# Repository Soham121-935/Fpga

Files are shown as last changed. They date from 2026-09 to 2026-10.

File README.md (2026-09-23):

# SV-16 Rev A — 16-Bit FPGA Microcontroller

SV-16 Rev A is a custom 16-bit microcontroller designed from the ground up in synthesizable SystemVerilog for FPGA deployment, specifically targeting the **Lattice ECP5 LFE5U-12F-6TG144C** FPGA.

The project encompasses the complete processor system:
- 16-bit RISC/load-store datapath with 8 general-purpose registers (`R0`–`R7`)
- Dedicated program counter (`PC`), instruction register (`IR`), status register (`SR`), and stack pointer (`SP`)
- 16-bit ALU (arithmetic, logic, shifts, multiply, divide) with Z, C, N, V flag updates
- Memory-mapped system bus with block RAM and integrated peripherals (GPIO, Timer, PWM, UART, SPI, I²C)
- Synthesizable RTL, comprehensive self-checking testbenches, and hardware verification suite

---

## Target Hardware Specification

- **Target FPGA**: Lattice Semiconductor ECP5
- **Part Number**: `LFE5U-12F-6TG144C`
- **Package**: 144-pin TQFP
- **Speed Grade**: -6
- **HDL Language**: SystemVerilog (`.sv`, `.v`)
- **Synthesis Target**: Lattice Diamond / Project Trellis (Yosys + nextpnr-ecp5)

---

## Repository Structure

```text
.
├── docs/                     # Architectural specifications and design records
│   ├── ARCHITECTURE_DECISIONS.md # Formal architectural decisions (ADRs)
│   ├── BUS_ARCHITECTURE.md      # Memory bus protocol, timing, and arbitration
│   ├── CPU_ARCHITECTURE.md      # CPU registers, datapath, and FSM lifecycle
│   ├── FPGA.md                  # Lattice ECP5 target specifics, clock, constraints
│   ├── ISA.md                   # Complete instruction set definition & opcodes
│   ├── MEMORY_MAP.md            # Memory spaces, address decoding, peripheral map
│   ├── OPEN_QUESTIONS.md        # Tracked architectural questions & ambiguities
│   ├── PERIPHERALS.md           # Specification for GPIO, Timer, PWM, UART, SPI, I2C
│   ├── PROJECT_STATUS.md        # Current phase status and roadmap tracking
│   ├── RESET_AND_CLOCK.md       # Reset domains, power-on sequencing, clocking
│   └── VERIFICATION.md          # Verification strategy, test plans, regression harness
├── rtl/                      # Synthesizable SystemVerilog source files
├── simulation/               # Simulation testbenches and test harnesses
│   ├── unit/                 # Unit testbenches for individual modules
│   └── regression/           # Full CPU and peripheral integration testbenches
├── firmware/                 # SV-16 assembly and C firmware
│   ├── drivers/              # Low-level peripheral drivers
│   └── examples/             # Application examples (GPIO, PWM, Motor control)
├── constraints/              # FPGA constraint files (.lpf for Lattice ECP5)
└── scripts/                  # Build, test, and verification automation scripts
```

---

## Architectural Principles

1. **No Invented Architecture**: Every feature, instruction encoding, register address, and bus protocol is explicitly documented in `docs/` before implementation.
2. **Layer-by-Layer Incremental Construction**: Bottom-up development from register file and ALU up through control unit, memory, peripherals, and firmware.
3. **Hardware Target Primacy**: All RTL is synthesizable for the Lattice ECP5 target; simulation models do not replace synthesizable logic.
4. **Automated Verification**: Every module has a dedicated self-checking testbench covering standard cases and corner cases.

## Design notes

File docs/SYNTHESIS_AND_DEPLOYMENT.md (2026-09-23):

# SV-16 Rev A — Synthesis, Implementation & Physical Deployment Guide

This guide details the complete procedure for synthesizing the SV-16 Rev A microcontroller, closing timing, and deploying the bitstream to the target **Lattice ECP5 LFE5U-12F-6TG144C** FPGA hardware.

---

## 1. Hardware Target Specifications

- **Device**: Lattice ECP5 `LFE5U-12F`
- **Package**: 144-pin TQFP (`144TQFP`, 0.5 mm pitch)
- **Speed Grade**: `-6`
- **Operating Voltage**: 1.1V Core, 3.3V I/O Banks
- **Primary Clock**: 25.0 MHz onboard oscillator connected to dedicated PCLK pin `P63`
- **Physical Constraints**: `constraints/ecp5_144tqfp.lpf`

---

## 2. FPGA Resource Utilization Estimates

The SV-16 Rev A design is optimized for high resource efficiency on the 12K LUT ECP5:

| Resource Type | Available on 12F | Estimated Used | Utilization (%) |
| :--- | :--- | :--- | :--- |
| **LUT4 Logic Elements** | 12,000 | ~1,650 | ~13.8% |
| **Registers (Flip-Flops)**| 12,000 | ~780 | ~6.5% |
| **sysMEM DP16KD Blocks**| 32 blocks (576 Kb) | 8 blocks (128 Kb) | 25.0% |
| **sysDSP Multiplier Slices**| 28 slices | 1 slice (16×16 MUL) | 3.6% |
| **I/O Pins** | Up to 118 | 12 pins | ~10.2% |

Ample FPGA resources remain available for further memory expansion or additional accelerators in Rev B.

---

## 3. Toolchain Option A: Open-Source Flow (Project Trellis)

The open-source flow uses **Yosys**, **nextpnr-ecp5**, and **Project Trellis**:

### Step 1: Synthesis with Yosys
```bash
yosys -p "read_verilog -sv rtl/*.sv; synth_ecp5 -top sv16_top -json sv16_top.json"
```

### Step 2: Place & Route with nextpnr-ecp5
```bash
nextpnr-ecp5 \
    --12k \
    --package TQFP144 \
    --speed 6 \
    --json sv16_top.json \
    --lpf constraints/ecp5_144tqfp.lpf \
    --textcfg sv16_top_out.config
```

### Step 3: Bitstream Packing with ecppack
```bash
ecppack --compress sv16_top_out.config sv16_top.bit
```

### Step 4: Programming the FPGA
```bash
openFPGALoader -b ecp5 sv16_top.bit
```

Or using `make`:
```bash
make bitstream
make prog
```

---

## 4. Toolchain Option B: Commercial Flow (Lattice Diamond)

1. Launch **Lattice Diamond**.
2. Open or create project `sv16_rev_a.ldf`.
3. Select Part:
   - Family: `ECP5U`
   - Device: `LFE5U-12F`
   - Performance Grade: `-6`
   - Package: `TQFP144`
4. Add all SystemVerilog files from `rtl/*.sv`.
5. Add constraint file `constraints/ecp5_144tqfp.lpf`.
6. Run **Synthesize Design** (Synplify Pro or LSE).
7. Run **Translate Design**, **Map Design**, and **Place & Route Design**.
8. Verify Static Timing Analysis (STA) reports zero timing violations against the 25.0 MHz constraint (Period = 40.0 ns, slack > +15.0 ns typical).
9. Run **Export Files** to generate JEDEC / Bitstream (`sv16_top.bit`).
10. Open **Lattice Diamond Programmer** and write the bitstream to internal SRAM or onboard SPI Flash.

---

## 5. Physical Electrical Hardware Connection (Bench Test)

```text
 ┌─────────────────────────┐               ┌──────────────────────────┐
 │   Lattice ECP5 Board    │               │  External Motor Driver   │
 │   (LFE5U-12F TQFP144)   │               │   (e.g., L298N / DRV)    │
 │                         │               │                          │
 │  Pin P100 (PWM Out)     ├──────────────►│ IN1 / PWM (Speed)        │
 │  Pin P101 (DIR1)        ├──────────────►│ IN2 / DIR (Phase A)      │
 │  Pin P102 (DIR2)        ├──────────────►│ IN3 / DIR (Phase B)      │
 │  Pin P103 (FAULT_N)     │◄──────────────┤ Fault / Overtemp Out     │
 │                         │               │                          │
 │  GND                    ├───────────────┤ GND (Common Ground)      │
 └─────────────────────────┘               └────────────┬─────────────┘
                                                        │
                                                        ▼
                                                ┌───────────────┐
                                                │   DC Motor    │
                                                │   (12V / 24V) │
                                                └───────────────┘
```

### Critical Safety Precautions:
1. **Common Ground**: Ensure the FPGA digital ground and motor driver ground are securely connected.
2. **Flyback Diodes**: Ensure inductive kickback clamp diodes (flyback diodes) are present across motor terminals.
3. **Power Isolation**: Never power the motor directly from the FPGA development board's 3.3V or 5V rail; use an isolated bench power supply for the motor driver stage.
4. **Hardware Emergency Shutdown**: Verify that pulling pin `P103` (`motor_fault_n`) low immediately inhibits PWM output and halts motor rotation.

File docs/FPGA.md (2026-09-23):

# SV-16 Rev A — Lattice ECP5 Target Specification

---

## 1. Device Hardware Details

```text
Manufacturer:    Lattice Semiconductor
Family:          ECP5 (Low-Cost, High-Performance)
Device:          LFE5U-12F
Full Part Number:LFE5U-12F-6TG144C
Package:         144-pin TQFP (0.5 mm pin pitch)
Speed Grade:     -6 (Commercial Temperature Range: 0°C to 85°C)
Core Voltage:    1.1V
I/O Banks:       8 I/O Banks (3.3V LVCMOS capable)
```

---

## 2. On-Chip Resources

- **LUT4 Logic Elements**: 12,000 LUTs
- **sysMEM Block RAM**: 32 DP16KD blocks (576 Kbits total)
  - Configurable as True Dual-Port, Pseudo Dual-Port, or Single-Port RAM/ROM.
  - Initialized with SV-16 boot firmware via `$readmemh` or bitstream initialization.
- **sysDSP Slices**: 28 Multiplier (18×18) blocks, ideal for single-cycle 16-bit ALU `MUL` operation.
- **sysCLOCK PLLs**: 2 General Purpose Phase-Locked Loops.
- **General Purpose I/O Pins**: Up to 118 user I/O pins available in 144 TQFP package.

---

## 3. Physical Pin Constraints Overview

Constraint definitions reside in `constraints/ecp5_144tqfp.lpf` (Lattice Preference Format):
- Clock Pin: `25 MHz` dedicated primary clock input.
- Reset Pin: Active-low push button input with internal pull-up.
- UART Pins: `uart_tx` (output), `uart_rx` (input with pull-up).
- Status LEDs: 4 to 8 dedicated active-low or active-high LEDs connected to GPIO.
- Motor Control Pins:
  - `pwm_out`: High-speed PWM switching pin to external gate driver / H-Bridge input.
  - `motor_dir1`, `motor_dir2`: Direction control GPIO outputs.
  - `motor_fault_n`: Emergency hardware shutdown input pin.

*Electrical Safety Warning*: Under no circumstances shall motor coils or inductive loads be connected directly to FPGA pins. An external driver stage (such as an L298N, DRV8833, or discrete MOSFET H-Bridge) with freewheeling flyback diodes and adequate decoupling capacitors must be used.

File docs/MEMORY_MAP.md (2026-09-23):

# SV-16 Rev A — Memory Map & Address Decoding

---

## 1. Address Space Overview

The SV-16 Rev A processor utilizes a unified 16-bit word-addressed memory map providing direct access to 64K words (`0x0000` to `0xFFFF`).

```text
0x0000 ┌────────────────────────────────────────┐
       │ Vector Table & Program / Code RAM       │
       │ (4K Words: 0x0000 - 0x0FFF)             │
0x1000 ├────────────────────────────────────────┤
       │ Data RAM & Stack Space                  │
       │ (4K Words: 0x1000 - 0x1FFF)             │
0x2000 ├────────────────────────────────────────┤
       │ Expansion Memory / Unmapped             │
       │ (0x2000 - 0xEFFF)                       │
0xF000 ├────────────────────────────────────────┤
       │ Memory-Mapped I/O Peripherals           │
       │ (4K Words: 0xF000 - 0xFFFF)             │
0xFFFF └────────────────────────────────────────┘
```

---

## 2. On-Chip BRAM Allocation for Lattice ECP5-12F

The **Lattice ECP5 LFE5U-12F** contains 32 sysMEM DP16KD block RAMs (each 18 Kbit = 16K data bits + 2K parity bits), providing a total of 576 Kbits (~36K 16-bit words).

For Rev A baseline implementation:
- **Program & Data RAM**: Initialized to 8K words (16 KB) internal dual-port / single-port BRAM (`0x0000`–`0x1FFF`).
  - `0x0000`–`0x0FFF` (4K words): Code & Read-Only Constants
  - `0x1000`–`0x1FFE` (4K words): General Data RAM
  - `0x1FFF` down to `0x1A00`: System Call & Return Stack (Full-descending stack, default initial `SP = 0x1FFE`)

---

## 3. Peripheral Memory Map (`0xF000` to `0xFFFF`)

Peripherals are mapped into individual 64-word blocks (`0x0040` words per peripheral):

| Base Address | Peripheral | Description | Registers Defined |
| :--- | :--- | :--- | :--- |
| `0xF000` | **System Control / Core** | CPU status, clocks, reset flags | `SYS_STATUS`, `SYS_CTRL` |
| `0xF010` | **GPIO Controller** | 16-bit General Purpose I/O | `GPIO_DATA`, `GPIO_DIR`, `GPIO_SET`, `GPIO_CLR` |
| `0xF020` | **Timer 0** | 16-bit hardware periodic timer | `TMR0_CNT`, `TMR0_CMP`, `TMR0_CTRL`, `TMR0_STAT` |
| `0xF030` | **PWM Controller 0** | Motor/LED pulse width modulation | `PWM0_PERIOD`, `PWM0_DUTY`, `PWM0_CTRL` |
| `0xF040` | **UART 0** | Asynchronous serial transceiver | `UART0_DATA`, `UART0_STATUS`, `UART0_BAUD`, `UART0_CTRL` |
| `0xF050` | **SPI Controller 0**| Synchronous serial peripheral | `SPI0_DATA`, `SPI0_STATUS`, `SPI0_CTRL`, `SPI0_CLKDIV` |
| `0xF060` | **I2C Controller 0**| Inter-Integrated Circuit master | `I2C0_DATA`, `I2C0_STATUS`, `I2C0_CTRL`, `I2C0_CLKDIV` |
| `0xF070`–`0xFFFF` | Reserved | Reserved for Rev B / future peripherals | - |

---

## 4. Detailed Peripheral Register Offsets

### GPIO Controller (`0xF010`)
- `0xF010`: `GPIO_DATA` — Read: Pin input state. Write: Output latch value.
- `0xF011`: `GPIO_DIR`  — Direction: `1` = Output, `0` = Input.
- `0xF012`: `GPIO_SET`  — Atomic pin set (writing `1` sets corresponding pin high).
- `0xF013`: `GPIO_CLR`  — Atomic pin clear (writing `1` clears corresponding pin low).

### Timer 0 Controller (`0xF020`)
- `0xF020`: `TMR0_CNT`  — Current 16-bit counter value (R/W).
- `0xF021`: `TMR0_CMP`  — 16-bit compare match register (R/W).
- `0xF022`: `TMR0_CTRL` — Control register:
  - Bit 0: `EN` (Timer enable)
  - Bit 1: `AUTO_RELOAD` (Reset counter to 0 on match)
  - Bit 2: `IE` (Interrupt enable on match)
  - Bits 7-4: Prescaler division select (1, 2, 4, 8, 16, 64, 256, 1024)
- `0xF023`: `TMR0_STAT` — Status register:
  - Bit 0: `MATCH` (Set when `CNT == CMP`, write 1 to clear)

### PWM Controller 0 (`0xF030`)
- `0xF030`: `PWM0_PERIOD` — 16-bit period value (sets PWM frequency).
- `0xF031`: `PWM0_DUTY`   — 16-bit duty cycle threshold (high when `counter < duty`).
- `0xF032`: `PWM0_CTRL`   — Control:
  - Bit 0: `EN` (PWM output enable)
  - Bit 1: `POL` (0 = active high, 1 = active low)
  - Bit 2: `FAULT` (Emergency motor brake / shutdown state)

### UART 0 Controller (`0xF040`)
- `0xF040`: `UART0_DATA`   — Read: RX byte [7:0]. Write: TX byte [7:0].
- `0xF041`: `UART0_STATUS` — Status:
  - Bit 0: `TX_READY` (1 = Ready to accept new transmit byte)
  - Bit 1: `RX_VALID` (1 = Receive byte waiting in buffer)
  - Bit 2: `OVERRUN_ERR` (1 = Receive overflow error)
  - Bit 3: `FRAME_ERR` (1 = Framing error)
- `0xF042`: `UART0_BAUD`   — 16-bit baud rate clock divisor (`clk_freq / baud_rate`).
- `0xF043`: `UART0_CTRL`   — Control:
  - Bit 0: `TX_EN`
  - Bit 1: `RX_EN`
  - Bit 2: `TX_IE` (TX interrupt enable)
  - Bit 3: `RX_IE` (RX interrupt enable)

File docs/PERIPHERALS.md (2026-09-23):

# SV-16 Rev A — Peripheral Subsystem Architecture

---

## 1. Scope

This document defines the hardware peripheral architecture for SV-16 Rev A. Peripherals provide the bridge between CPU instructions and real-world electrical systems.

The primary target demonstration is:
```text
SV-16 CPU Firmware
        │
    (System Bus)
        │
   PWM Peripheral
        │
    FPGA Pin (TQFP-144)
        │
  External Motor Driver (H-Bridge)
        │
     DC Motor
```

---

## 2. Peripheral Specifications

### 2.1 GPIO Controller (`0xF010`)
- **Port Width**: 16 bidirectional I/O pins (`gpio_pin[15:0]`).
- **Input Filtering / Synchronizer**: 2-stage flip-flop synchronizer on all input pins to prevent metastability into internal logic.
- **Direction Register (`GPIO_DIR`)**:
  - `1`: Pin is configured as digital output (`gpio_oen = 1`).
  - `0`: Pin is configured as high-impedance digital input (`gpio_oen = 0`).
- **Atomic Operations (`GPIO_SET` / `GPIO_CLR`)**:
  - Eliminates read-modify-write race conditions when controlling individual pins from firmware.
  - Writing `1` to `GPIO_SET[k]` asserts pin `k` high.
  - Writing `1` to `GPIO_CLR[k]` asserts pin `k` low.

### 2.2 Hardware Timer 0 (`0xF020`)
- **Counter Width**: 16 bits (`0` to `65535`).
- **Clock Prescaler**: Configurable power-of-two clock division (1, 2, 4, 8, 16, 64, 256, 1024).
- **Match Register**: Triggers interrupt or auto-reload when `counter == compare`.
- **Interrupt Output**: Asserts level-sensitive interrupt line to core interrupt controller.

### 2.3 Hardware PWM Controller 0 (`0xF030`)
- **Resolution**: 16-bit counter resolution.
- **Clock Base**: System clock divided by programmable prescaler.
- **Operation**:
  - Counter increments each tick from `0` to `PWM_PERIOD - 1`.
  - When counter wraps to `0`, PWM output is set high.
  - When counter reaches `PWM_DUTY`, PWM output is set low.
  - Generates glitch-free, high-resolution duty cycles from 0.0% to 100.0%.
- **Safety Fault Input**: External hardware emergency stop or overcurrent detect pin immediately forces PWM outputs low asynchronously.

### 2.4 Hardware UART 0 (`0xF040`)
- **Baud Generation**: 16-bit programmable fractional/integer divider.
  - Default: 115,200 baud from 25 MHz system clock (`divisor = 25,000,000 / 115,200 ≈ 217`).
- **Framing**: 8 data bits, 1 stop bit, no parity (8-N-1).
- **Buffering**: Single-byte double-buffered TX and RX registers (with status flags for overrun and framing errors).

---

## 3. Peripheral Address Decoding Scheme

Address decoding is performed by examining `bus_addr[15:4]`:
- `16'hF01_` $\implies$ GPIO Controller
- `16'hF02_` $\implies$ Timer 0
- `16'hF03_` $\implies$ PWM Controller 0
- `16'hF04_` $\implies$ UART 0
- `16'hF05_` $\implies$ SPI 0
- `16'hF06_` $\implies$ I2C 0

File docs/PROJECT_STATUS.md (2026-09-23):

# SV-16 Rev A — Project Status

Last Updated: Phase 22 Completed — Complete Microcontroller & Verification Suite Verified

---

## Phase Progress Summary

| Phase | Description | Status | Verification State |
| :--- | :--- | :--- | :--- |
| **Phase 0** | Repository foundation & structure | **COMPLETED** | Standard directory layout & base docs created |
| **Phase 1** | Architecture definition & freeze | **COMPLETED** | Full ISA, CPU architecture, memory map, ADRs documented |
| **Phase 2** | SystemVerilog infrastructure & coding standards | **COMPLETED** | `sv16_pkg.sv`, `sv16_top.sv`, `CODING_STANDARDS.md` |
| **Phase 3** | Register file (8 × 16-bit) | **COMPLETED** | `sv16_regfile.sv` implemented & verified with `sv16_regfile_tb.sv` |
| **Phase 4** | ALU (16-bit arithmetic, logic, shift, mul, div) | **COMPLETED** | `sv16_alu.sv` implemented & verified with `sv16_alu_tb.sv` |
| **Phase 5** | Status register (Z, C, N, V) | **COMPLETED** | `sv16_status_reg.sv` implemented & verified with `sv16_status_reg_tb.sv` |
| **Phase 6** | Program Counter (PC) | **COMPLETED** | `sv16_pc.sv` implemented & verified with `sv16_pc_tb.sv` |
| **Phase 7** | Instruction register & decoder | **COMPLETED** | `sv16_decoder.sv` implemented & verified with `sv16_decoder_tb.sv` |
| **Phase 8** | Control unit | **COMPLETED** | `sv16_control_unit.sv` implemented & verified with `sv16_control_unit_tb.sv` |
| **Phase 9** | Minimal CPU integration | **COMPLETED** | `sv16_core.sv` integrated & verified with test program in `sv16_cpu_tb.sv` |
| **Phase 10** | Memory subsystem (BRAM + Bus) | **COMPLETED** | `sv16_ram.sv` & `sv16_bus_interconnect.sv` verified in `sv16_ram_tb.sv` |
| **Phase 11** | Stack & subroutines (SP, PUSH, POP, CALL, RET) | **COMPLETED** | Stack semantics & nested calls verified in `sv16_stack_subroutine_tb.sv` |
| **Phase 12** | Branching logic | **COMPLETED** | Conditional branches & loops verified in `sv16_branch_tb.sv` |
| **Phase 13** | GPIO peripheral | **COMPLETED** | `sv16_gpio.sv` implemented with atomic SET/CLR & verified in `sv16_gpio_tb.sv` |
| **Phase 14** | Hardware Timer | **COMPLETED** | `sv16_timer.sv` with compare match & IRQ verified in `sv16_timer_tb.sv` |
| **Phase 15** | Hardware PWM | **COMPLETED** | `sv16_pwm.sv` with emergency fault shutdown verified in `sv16_pwm_tb.sv` |
| **Phase 16** | Hardware UART | **COMPLETED** | `sv16_uart.sv` 8-N-1 transceiver verified in `sv16_uart_tb.sv` |
| **Phase 17** | Interrupt controller interface | **COMPLETED** | Core interrupt lines (Timer, UART, GPIO) integrated into SoC |
| **Phase 18** | External peripheral interconnect expansion | **COMPLETED** | Bus interconnect ports reserved & mapped |
| **Phase 19** | Firmware layer & drivers | **COMPLETED** | Hardware register header `sv16_hardware.h` created |
| **Phase 20** | FPGA top-level integration (`sv16_top.sv`) | **COMPLETED** | Complete synthesizable SoC top connecting all units to Lattice ECP5 pads |
| **Phase 21** | First real hardware test (LED blink via firmware) | **COMPLETED** | Full system execution verified in `sv16_top_tb.sv` |
| **Phase 22** | Motor control demonstration (PWM + Driver + DC Motor)| **COMPLETED** | Firmware `firmware/examples/motor_control.c` & PWM verified |

---

## Verification Suite Summary
- Total Automated Test Checks Passed: **45**
- Test Failures: **0**
- Test Suites:
  - 30 SystemVerilog structural and syntax checks across all RTL and testbench modules
  - 15 functional verification testbenches covering ALU, decoder, control unit, regfile, PC, status register, RAM, bus interconnect, stack, branching, GPIO, timer, PWM, UART, and full SoC execution

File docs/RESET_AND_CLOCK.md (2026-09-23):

# SV-16 Rev A — Reset and Clock Architecture

---

## 1. Target Clock Architecture

- **FPGA Device**: Lattice ECP5 `LFE5U-12F-6TG144C`
- **Primary System Clock Frequency (`clk`)**: **25.0 MHz** (Period = 40.0 ns)
- **Clock Source**: Onboard 25 MHz oscillator connected to dedicated primary clock pin (PCLK) on Lattice ECP5.
- **Clock Distribution**: Routed via Lattice ECP5 primary clock routing networks (`DCS` / `PCLK` tree) for ultra-low skew (<150 ps).
- **Design Philosophy**: Prioritize timing margin, signal integrity, and reliable multi-peripheral operation over excessive clock speed. A 25 MHz system clock provides ample performance for 16-bit real-time motor PID loops, sensor reading, and UART communications.

---

## 2. Reset Architecture

### Reset Inputs and Conditions
1. **External Hardware Reset Pin (`ext_rst_n`)**: Active-low physical push button or supervisory reset IC pin.
2. **Power-On Reset (POR)**: Internal Lattice ECP5 power-good detector.

### Reset Synchronization
- An asynchronous assert, synchronous de-assert reset bridge (2-stage flip-flop synchronizer) ensures clean startup without reset race conditions or metastability:
```text
           VCC
            │
          ┌─┴─┐   ┌───┐   ┌───┐
ext_rst_n─┤ D ├───┤ D ├───┤ D ├──► sys_rst_n (to all CPU logic)
          │   │   │   │   │   │
clk ──────┤CLK├───┤CLK├───┤CLK│
          └───┘   └───┘   └───┘
```

### Architectural State on Reset Release
- **`PC`**: Reset to `0x0000` (Vector 0: Reset Handler).
- **`IR`**: Reset to `16'h0000` (`NOP`).
- **`SR`**: Reset to `16'h0000` (Flags cleared, interrupts disabled).
- **`SP`**: Reset to `16'h1FFE` (Top of internal data RAM).
- **Registers `R0`–`R7`**: Reset to `16'h0000`.
- **CPU Control FSM**: State set to `S_FETCH`.
- **System Bus**: `bus_req = 0`, `bus_we = 0`.
- **Peripherals (GPIO, PWM, Timer, UART)**: Outputs disabled, all pins high-Z inputs, PWM duty 0%.

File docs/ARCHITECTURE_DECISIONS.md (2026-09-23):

# SV-16 Rev A — Architecture Decisions Record (ADR)

This file tracks foundational architectural decisions made for the SV-16 Rev A microcontroller.

---

## ADR-001: Target Device and Toolchain Compatibility
- **Status**: **ACCEPTED**
- **Context**: The master specification explicitly selects the Lattice ECP5 `LFE5U-12F-6TG144C`. The design must synthesize both in Lattice Diamond and open-source Yosys + nextpnr-ecp5 environments.
- **Decision**: All RTL must adhere to standard synthesizable SystemVerilog (IEEE 1800-2012 subset widely supported by Yosys and Diamond Synplify Pro). Avoid vendor-proprietary macro instantiation in core CPU RTL; vendor primitives (like PLL or DP16KD) should be isolated in top-level wrappers (`rtl/fpga_wrappers/`).
- **Consequences**: RTL remains fully portable, simulatable with standard Verilog/SystemVerilog engines, and directly synthesizable on Lattice ECP5.

---

## ADR-002: Multi-Cycle FSM Control Architecture for Rev A
- **Status**: **ACCEPTED**
- **Context**: SV-16 Rev A prioritizes correctness, reliability, simplicity, and debuggability over maximum pipeline throughput (Section 11, Master Spec). A pipelined design introduces data hazards, forwarding logic, branch penalties, and complex stall logic that increases verification surface exponentially.
- **Decision**: SV-16 Rev A uses a multi-cycle synchronous FSM:
  1. `FETCH`: Read instruction word from memory at `PC`, latch into `IR`, increment `PC`.
  2. `DECODE`: Decode opcode, extract operand fields, read register file operands `Rs1` and `Rs2`. If instruction is 2-word, fetch immediate word.
  3. `EXECUTE`: Perform ALU operation or evaluate branch condition or compute memory effective address.
  4. `MEMORY`: Read or write bus memory if LOAD/STORE/PUSH/POP.
  5. `WRITEBACK`: Write result to destination register `Rd` in register file, update status flags in `SR`.
- **Consequences**: Eliminates pipeline hazards; guarantees deterministic execution; makes single-stepping and trace debugging straightforward.

---

## ADR-003: Register File Organization
- **Status**: **ACCEPTED**
- **Context**: Spec mandates 8 general-purpose registers: `R0`, `R1`, `R2`, `R3`, `R4`, `R5`, `R6`, `R7`, each 16 bits (128 bits total storage).
- **Decision**:
  - 2 asynchronous/synchronous read ports (`rdata1`, `rdata2`) with 3-bit addresses (`raddr1`, `raddr2`).
  - 1 synchronous write port (`wdata`) with 3-bit address (`waddr`) and active-high write enable (`wen`).
  - `R0` is a general read/write register (NOT hardwired to 0, matching standard 16-bit CISC/RISC architectures; clear operations can set `R0` explicitly).
- **Consequences**: Allows dual-operand instructions like `ADD Rd, Rs` or `ADD Rd, Rs1, Rs2` in a single execute cycle.

---

## ADR-004: Status Register (SR) Flag Definitions
- **Status**: **PROVISIONAL (Awaiting Final Signoff)**
- **Context**: Master instruction mandates architectural flags `Z` (Zero), `C` (Carry), `N` (Negative), and `V` (Overflow).
- **Decision**:
  - `SR[0]`: `Z` (Zero flag: set when ALU result == 0)
  - `SR[1]`: `C` (Carry flag: unsigned borrow/carry out of bit 15)
  - `SR[2]`: `N` (Negative flag: bit 15 of result)
  - `SR[3]`: `V` (Overflow flag: signed two's complement overflow)
  - `SR[7]`: `IE` (Global Interrupt Enable: 1 = enabled, 0 = disabled)
  - `SR[6:4]`, `SR[15:8]`: Reserved (read as 0)
- **Consequences**: Unambiguous hardware bit mapping and assembly flag condition testing.

---

## ADR-005: Memory Bus Organization
- **Status**: **PROVISIONAL (Awaiting Final Signoff)**
- **Context**: Need a simple, synthesizable, synchronous system bus connecting CPU to internal BRAM and memory-mapped peripherals.
- **Decision**: A unified 16-bit synchronous bus:
  - `bus_addr[15:0]`: 16-bit word address
  - `bus_wdata[15:0]`: 16-bit write data
  - `bus_rdata[15:0]`: 16-bit read data
  - `bus_we`: Write enable (1 = write, 0 = read)
  - `bus_req`: Bus access request strobe
  - `bus_ack`: Slave acknowledge (ready) signal
- **Consequences**: Zero wait-state access for single-cycle on-chip BRAM (`ack = 1`), wait-state support for slower peripheral access or UART FIFOs.

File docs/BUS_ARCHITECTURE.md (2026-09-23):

# SV-16 Rev A — System Bus Architecture

---

## 1. Bus Overview

The SV-16 system bus is a synchronous, master-slave 16-bit address and data bus optimized for FPGA implementation. It provides clean separation between the CPU execution core, internal memory blocks, and memory-mapped peripheral controllers.

```text
                  ┌────────────────────┐
                  │    SV-16 Core      │
                  │   (Bus Master)     │
                  └─────────┬──────────┘
                            │
              ┌─────────────┼─────────────┐
              │ addr[15:0]  │ wdata[15:0] │ rdata[15:0]
              │ req         │ we          │ ack
              ▼             ▼             ▼
  ┌──────────────────────────────────────────────────┐
  │                 Address Decoder                  │
  └───────────┬──────────────┬─────────────┬─────────┘
              │              │             │
              ▼              ▼             ▼
       ┌─────────────┐ ┌───────────┐ ┌───────────┐
       │   RAM 8K    │ │   GPIO    │ │   Timer   │ ...
       │ (0x0000 -   │ │ (0xF010 - │ │ (0xF020 - │
       │  0x1FFF)    │ │  0xF013)  │ │  0xF023)  │
       └─────────────┘ └───────────┘ └───────────┘
```

---

## 2. Bus Signal Definitions

All signals are synchronous to the positive edge of `clk`.

| Signal Name | Direction (Master perspective) | Width | Description |
| :--- | :--- | :--- | :--- |
| `clk` | Master / System | 1 bit | Master synchronous clock |
| `rst_n` | Master / System | 1 bit | Active-low synchronous/asynchronous system reset |
| `bus_addr` | Master $\to$ Slaves | 16 bits | Word address bus (`0x0000` to `0xFFFF`) |
| `bus_wdata`| Master $\to$ Slaves | 16 bits | Write data bus from CPU to peripherals/RAM |
| `bus_rdata`| Slaves $\to$ Master | 16 bits | Read data bus multiplexed from selected slave |
| `bus_we` | Master $\to$ Slaves | 1 bit | Write Enable: `1` = Write cycle, `0` = Read cycle |
| `bus_req` | Master $\to$ Slaves | 1 bit | Bus Request: Asserted high when master initiates transfer |
| `bus_ack` | Slaves $\to$ Master | 1 bit | Bus Acknowledge: Asserted high by slave when transfer complete |

---

## 3. Bus Transaction Timing

### Single-Cycle Read Access (e.g. Block RAM or Single-Cycle Peripheral Register)
```text
          Cycle 0       Cycle 1       Cycle 2
clk     : ___/‾‾‾\___/‾‾‾\___/‾‾‾\___/‾‾‾\___
bus_addr: ------<    ADDR 0x1000     >-------
bus_req : ____________/‾‾‾‾‾‾‾‾‾‾‾\__________
bus_we  : ___________________________________ (Read = 0)
bus_rdata: -------------<   DATA_VAL   >------
bus_ack : ____________/‾‾‾‾‾‾‾‾‾‾‾\__________
```
- At Clock Cycle 1 posedge: CPU asserts `bus_req = 1`, `bus_we = 0`, sets `bus_addr`.
- Slave decodes address, immediately returns `bus_ack = 1` and valid `bus_rdata`.
- At Clock Cycle 2 posedge: CPU captures `bus_rdata`, deasserts `bus_req`.

### Multi-Cycle Access with Wait-States (e.g. External SPI / UART FIFO)
- If a slave requires multiple clock cycles to complete a transfer (or synchronize clock domains), it holds `bus_ack = 0` until ready.
- The CPU FSM stalls in its current `S_FETCH` or `S_MEMORY` state while `bus_req == 1 && bus_ack == 0`.
- Once the slave asserts `bus_ack = 1`, the transfer completes on the next rising clock edge.

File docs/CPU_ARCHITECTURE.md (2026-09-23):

# SV-16 Rev A — CPU Architecture Specification

---

## 1. Overview

SV-16 Rev A is a 16-bit register-oriented microprocessor designed for low-latency embedded control, timing, and motor peripheral actuation.

### Architectural Parameters
- **Data Bus Width**: 16 bits
- **Address Bus Width**: 16 bits (addressing up to 64K words)
- **General Purpose Registers**: 8 registers (`R0`–`R7`), 16 bits each
- **Dedicated Architectural Registers**:
  - `PC`: Program Counter (16-bit)
  - `IR`: Instruction Register (16-bit)
  - `SR`: Status Register (16-bit)
  - `SP`: Stack Pointer (16-bit)

---

## 2. Register Organization

### General Purpose Registers (GPR)

```text
 15                                                             0
┌────────────────────────────────────────────────────────────────┐
│                              R0                                │
├────────────────────────────────────────────────────────────────┤
│                              R1                                │
├────────────────────────────────────────────────────────────────┤
│                              R2                                │
├────────────────────────────────────────────────────────────────┤
│                              R3                                │
├────────────────────────────────────────────────────────────────┤
│                              R4                                │
├────────────────────────────────────────────────────────────────┤
│                              R5                                │
├────────────────────────────────────────────────────────────────┤
│                              R6                                │
├────────────────────────────────────────────────────────────────┤
│                              R7 (Frame/Temp or Scratch)        │
└────────────────────────────────────────────────────────────────┘
```

All 8 registers are general read/write registers.

### Special Registers

1. **Program Counter (`PC`)**:
   - Points to the current instruction address.
   - Power-on reset value: `0x0000`.
   - Increments by `1` per instruction word fetched (in word-addressed mode).
   - Updated on `JMP`, `CALL`, `RET`, conditional branch (`Bxx`), and interrupt entry/return.

2. **Instruction Register (`IR`)**:
   - Holds the current 16-bit instruction word during decode and execution.
   - For 2-word instructions, a secondary temporary register (`IMM_REG`) holds the immediate 16-bit data word.

3. **Status Register (`SR`)**:
   - Holds processor flags and CPU status bits:
     - `Bit 0 [Z]`: Zero flag. Set if ALU result == `0x0000`.
     - `Bit 1 [C]`: Carry / Borrow flag. Set on unsigned addition overflow or subtraction borrow.
     - `Bit 2 [N]`: Negative / Sign flag. Set if MSB of result (bit 15) == `1`.
     - `Bit 3 [V]`: Signed Overflow flag. Set if signed addition/subtraction wraps.
     - `Bit 7 [IE]`: Global Interrupt Enable.
     - `Bits [6:4], [15:8]`: Reserved (always read as 0).
   - Power-on reset value: `0x0000`.

4. **Stack Pointer (`SP`)**:
   - Points to the top of the system call/data stack in memory.
   - Power-on reset default: `0x0FFE` (top of internal 4K-word RAM block).
   - Decremented on `PUSH` and `CALL`; incremented on `POP` and `RET`.

---

## 3. Execution Pipeline & Multi-Cycle Control Flow

SV-16 uses a deterministic synchronous multi-cycle finite state machine (FSM).

```text
                     ┌───────────┐
                     │   RESET   │
                     └─────┬─────┘
                           │
                           ▼
                    ┌─────────────┐
        ┌───────────►    FETCH    │
        │           └──────┬──────┘
        │                  │
        │                  ▼
        │           ┌─────────────┐
        │           │   DECODE    │
        │           └──────┬──────┘
        │                  │
        │                  ├────────────────────────┐ (If 2-word instruction)
        │                  │                        │
        │                  │                        ▼
        │                  │                 ┌─────────────┐
        │                  │                 │  FETCH_IMM  │
        │                  │                 └──────┬──────┘
        │                  │                        │
        │                  ▼                        │
        │           ┌─────────────┐                 │
        │           │   EXECUTE   │◄────────────────┘
        │           └──────┬──────┘
        │                  │
        │         ┌────────┴────────┐
        │         ▼                 ▼
        │  ┌─────────────┐   ┌─────────────┐
        │  │   MEMORY    │   │  WRITEBACK  │
        │  └──────┬──────┘   └──────┬──────┘
        │         │                 │
        │         ▼                 │
        │  ┌─────────────┐          │
        │  │  WRITEBACK  │          │
        │  └──────┬──────┘          │
        │         │                 │
        └─────────┴─────────────────┘
```

### State Descriptions

1. **`S_FETCH`**:
   - `bus_addr <= PC`
   - `bus_req <= 1`, `bus_we <= 0`
   - Next state: When `bus_ack == 1`, `IR <= bus_rdata`, `PC <= PC + 1`, transit to `S_DECODE`.

2. **`S_DECODE`**:
   - Decode opcode in `IR`.
   - Read `Rs1` and `Rs2` from Register File.
   - If instruction requires a 16-bit immediate word (`LDI`, `JMP_IMM`, etc.), transition to `S_FETCH_IMM`.
   - Otherwise, transition to `S_EXECUTE`.

3. **`S_FETCH_IMM`**:
   - `bus_addr <= PC`
   - `bus_req <= 1`, `bus_we <= 0`
   - When `bus_ack == 1`, latches immediate value into internal register, `PC <= PC + 1`, transitions to `S_EXECUTE`.

4. **`S_EXECUTE`**:
   - ALU performs arithmetic/logic operation.
   - For branch instructions: evaluate condition flags in `SR`. If condition met: `PC <= target_addr`.
   - For register-to-register instructions: transition to `S_WRITEBACK`.
   - For memory access (`LOAD`, `STORE`, `PUSH`, `POP`): transition to `S_MEMORY`.

5. **`S_MEMORY`**:
   - Perform bus read or write:
     - `LOAD`: `bus_addr <= effective_addr`, `bus_req <= 1`, `bus_we <= 0`.
     - `STORE`: `bus_addr <= effective_addr`, `bus_wdata <= Rs`, `bus_req <= 1`, `bus_we <= 1`.
     - `PUSH`: `SP <= SP - 1`, `bus_addr <= SP - 1`, `bus_wdata <= Rs`, `bus_we <= 1`.
     - `POP`: `bus_addr <= SP`, `SP <= SP + 1`, `bus_we <= 0`.
   - On completion (`bus_ack == 1`):
     - If load/pop: transition to `S_WRITEBACK`.
     - If store/push: transition to `S_FETCH` for next instruction.

6. **`S_WRITEBACK`**:
   - Write computed ALU result or loaded memory data to `Rd` in Register File (`wen = 1`).
   - Latch updated ALU flags into `SR`.
   - Transition to `S_FETCH`.

---

## 4. Subroutines and Call/Return

- **`CALL <target>`**:
  - Pushes current `PC` (return address) onto stack (`SP <= SP - 1; MEM[SP] <= PC`).
  - Sets `PC <= target`.
- **`RET`**:
  - Pops return address from stack (`PC <= MEM[SP]; SP <= SP + 1`).

---

## 5. ALU Specification

The ALU is a 16-bit combinational/registered datapath component with operations:
1. `ADD`: Signed/unsigned 16-bit addition ($A + B$)
2. `SUB`: Signed/unsigned 16-bit subtraction ($A - B$)
3. `AND`: Bitwise AND ($A \ \& \ B$)
4. `OR`:  Bitwise OR ($A \ | \ B$)
5. `XOR`: Bitwise XOR ($A \ \text{^} \ B$)
6. `NOT`: Bitwise NOT ($\sim A$)
7. `SHL`: Logical shift left ($A \ll \text{imm/B}$)
8. `SHR`: Logical shift right ($A \gg \text{imm/B}$)
9. `INC`: Increment ($A + 1$)
10. `DEC`: Decrement ($A - 1$)
11. `MUL`: 16-bit integer multiplication ($A \times B$)
12. `DIV`: 16-bit unsigned integer division ($A / B$)

### Flag Calculation Rules
- **Zero Flag (`Z`)**: Set if `result == 16'h0000`.
- **Negative Flag (`N`)**: Set if `result[15] == 1'b1`.
- **Carry Flag (`C`)**:
  - Addition / INC: Set if carry out of bit 15 ($A + B > 65535$).
  - Subtraction / DEC: Set if borrow occurs ($A < B$).
  - Shifts: Set to the last bit shifted out.
- **Overflow Flag (`V`)**:
  - Signed addition: Set if $(A[15] == B[15]) \ \& \ (result[15] \ne A[15])$.
  - Signed subtraction: Set if $(A[15] \ne B[15]) \ \& \ (result[15] \ne A[15])$.
  - Division by zero: Set if divisor == 0.

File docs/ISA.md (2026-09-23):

# SV-16 Rev A — Instruction Set Architecture (ISA Rev A)

Status: **FROZEN PROVISIONAL FOR PHASE 1 REVIEW**

---

## 1. Instruction Formats

SV-16 uses 16-bit baseline instruction words. Certain instructions (e.g. 16-bit immediate loads, absolute long jumps) use an optional second 16-bit immediate word.

### Format R (Register-Register Operations)
```text
15    12 11   9 8    6 5    3 2    0
┌───────┬──────┬──────┬──────┬──────┐
│ Opcode│  Rd  │ Rs1  │ Rs2  │ SubOp│
└───────┴──────┴──────┴──────┴──────┘
  4-bit  3-bit  3-bit  3-bit  3-bit
```
- Used for 3-operand or 2-operand ALU operations (`Rd <= Rs1 OP Rs2`).

### Format I (Register-Immediate Operations)
```text
15    12 11   9 8                  0
┌───────┬──────┬────────────────────┐
│ Opcode│  Rd  │    Immediate (9-bit signed)
└───────┴──────┴────────────────────┘
  4-bit  3-bit         9-bit
```
- Used for short immediate addition, subtraction, and comparison (`-256` to `+255`).

### Format M (Memory Load / Store)
```text
15    12 11   9 8    6 5            0
┌───────┬──────┬──────┬─────────────┐
│ Opcode│  Rd  │  Rb  │ Offset (6b) │
└───────┴──────┴──────┴─────────────┘
  4-bit  3-bit  3-bit     6-bit
```
- Address calculation: `Effective Address = Rb + sign_extend(Offset)`.
- If `Rb == 000`, offset acts as small direct address or base `R0`.

### Format B (Branch / Jump)
```text
15    12 11   8 7                  0
┌───────┬──────┬────────────────────┐
│ Opcode│ Cond │    Offset (8-bit signed)
└───────┴──────┴────────────────────┘
  4-bit  4-bit         8-bit
```
- Branch condition evaluates flags in Status Register (`SR`).
- Target: `PC <= PC + sign_extend(Offset)`.

### Format S (Special / Stack / Control)
```text
15    12 11   9 8                  0
┌───────┬──────┬────────────────────┐
│ Opcode│  Rx  │      Sub-Opcode    │
└───────┴──────┴────────────────────┘
  4-bit  3-bit         9-bit
```
- Used for `PUSH Rx`, `POP Rx`, `CALL`, `RET`, `NOP`, `HALT`, `RETI`.

---

## 2. Register Encodings

| Register Name | Register Code (`Rd` / `Rs` / `Rb`) | Description |
| :--- | :--- | :--- |
| `R0` | `3'b000` | General Purpose Register 0 |
| `R1` | `3'b001` | General Purpose Register 1 |
| `R2` | `3'b010` | General Purpose Register 2 |
| `R3` | `3'b011` | General Purpose Register 3 |
| `R4` | `3'b100` | General Purpose Register 4 |
| `R5` | `3'b101` | General Purpose Register 5 |
| `R6` | `3'b110` | General Purpose Register 6 |
| `R7` | `3'b111` | General Purpose Register 7 |

---

## 3. Opcode Assignment Table

| Opcode [15:12] | Mnemonic | Format | Description | Flag Effects |
| :--- | :--- | :--- | :--- | :--- |
| `0000` (`0x0`) | `NOP` / `CTRL` | S | System Control (`NOP`, `HALT`, `EI`, `DI`, `RETI`) | None |
| `0001` (`0x1`) | `ALU_RR` | R | Register-Register ALU operations (SubOp in [2:0]) | Z, C, N, V |
| `0010` (`0x2`) | `ADDI` | I | Add Immediate: `Rd <= Rd + sign_ext(imm9)` | Z, C, N, V |
| `0011` (`0x3`) | `SUBI` | I | Subtract Immediate: `Rd <= Rd - sign_ext(imm9)` | Z, C, N, V |
| `0010` (`0x4`) | `LDI` | S (2-word) | Load 16-bit Immediate: `Rd <= imm16` (word 2) | Z, N |
| `0101` (`0x5`) | `LOAD` | M | Memory Load: `Rd <= MEM[Rb + offset]` | Z, N |
| `0110` (`0x6`) | `STORE`| M | Memory Store: `MEM[Rb + offset] <= Rd` | None |
| `0111` (`0x7`) | `MOV` | R | Register Copy: `Rd <= Rs1` | Z, N |
| `1000` (`0x8`) | `BRANCH`| B | Conditional Branch relative to PC | None |
| `1001` (`0x9`) | `JMP` | S (2-word) | Unconditional Jump absolute: `PC <= imm16` | None |
| `1010` (`0xA`) | `CALL` | S (2-word) | Call Subroutine: `PUSH PC; PC <= imm16` | None |
| `1011` (`0xB`) | `RET` | S | Return from Subroutine: `POP PC` | None |
| `1100` (`0xC`) | `PUSH` | S | Push register to stack: `PUSH Rx` | None |
| `1101` (`0xD`) | `POP` | S | Pop register from stack: `POP Rx` | Z, N |
| `1110` (`0xE`) | `CMP` | R | Compare: compute `Rs1 - Rs2`, discard result | Z, C, N, V |
| `1111` (`0xF`) | `EXT_ALU` | R | Extended ALU (MUL, DIV, Shifts) | Z, C, N, V |

---

## 4. Sub-Opcode Mappings for ALU Operations

### Primary ALU SubOpcodes (`Opcode = 0x1`, Format R, bits [2:0]):
- `3'b000`: `ADD  Rd, Rs1, Rs2` — `Rd <= Rs1 + Rs2`
- `3'b001`: `SUB  Rd, Rs1, Rs2` — `Rd <= Rs1 - Rs2`
- `3'b010`: `AND  Rd, Rs1, Rs2` — `Rd <= Rs1 & Rs2`
- `3'b011`: `OR   Rd, Rs1, Rs2` — `Rd <= Rs1 | Rs2`
- `3'b100`: `XOR  Rd, Rs1, Rs2` — `Rd <= Rs1 ^ Rs2`
- `3'b101`: `NOT  Rd, Rs1`      — `Rd <= ~Rs1`
- `3'b110`: `INC  Rd, Rs1`      — `Rd <= Rs1 + 1`
- `3'b111`: `DEC  Rd, Rs1`      — `Rd <= Rs1 - 1`

### Extended ALU SubOpcodes (`Opcode = 0xF`, Format R, bits [2:0]):
- `3'b000`: `SHL  Rd, Rs1, Rs2` (or imm in `Rs2` field) — Logical Shift Left
- `3'b001`: `SHR  Rd, Rs1, Rs2` (or imm in `Rs2` field) — Logical Shift Right
- `3'b010`: `MUL  Rd, Rs1, Rs2` — Unsigned 16-bit Multiply (`Rd <= (Rs1 * Rs2)[15:0]`)
- `3'b011`: `DIV  Rd, Rs1, Rs2` — Unsigned 16-bit Division (`Rd <= Rs1 / Rs2`)
- `3'b100`: `MOD  Rd, Rs1, Rs2` — Unsigned 16-bit Modulo (`Rd <= Rs1 % Rs2`)
- `3'b101` to `3'b111`: Reserved for future arithmetic expansion

---

## 5. Branch Condition Codes (Format B, `Cond` field bits [11:8])

| Cond [11:8] | Mnemonic | Condition Name | Test in Status Register |
| :--- | :--- | :--- | :--- |
| `4'b0000` | `BRA` | Always / Unconditional | Always true (`1`) |
| `4'b0001` | `BEQ` | Equal / Zero | `Z == 1` |
| `4'b0010` | `BNE` | Not Equal / Non-Zero | `Z == 0` |
| `4'b0011` | `BC` / `BLO` | Carry Set / Below (Unsigned <) | `C == 1` |
| `4'b0100` | `BNC` / `BHS`| Carry Clear / Higher or Same (Unsigned >=) | `C == 0` |
| `4'b0101` | `BN` / `BMI` | Negative / Minus | `N == 1` |
| `4'b0110` | `BP` / `BPL` | Positive / Plus | `N == 0` |
| `4'b0111` | `BVS` | Overflow Set | `V == 1` |
| `4'b1000` | `BVC` | Overflow Clear | `V == 0` |
| `4'b1001` | `BLT` | Less Than (Signed <) | `(N ^ V) == 1` |
| `4'b1010` | `BGE` | Greater or Equal (Signed >=) | `(N ^ V) == 0` |
| `4'b1011` | `BLE` | Less or Equal (Signed <=) | `(Z \| (N ^ V)) == 1` |
| `4'b1100` | `BGT` | Greater Than (Signed >) | `(Z \| (N ^ V)) == 0` |
| `4'b1101`–`4'b1111` | Reserved | Reserved for future condition codes | Always false (`0`) |

---

## 6. Illegal Instruction & Reserved Opcode Handling

Any undefined opcode or sub-opcode (such as reserved condition codes or reserved ALU operations) will:
1. Trigger an illegal instruction exception (if interrupt vector initialized), OR
2. Treat the instruction as a `NOP` without modifying architectural registers or flags, asserting an `illegal_instr` debug flag on the CPU core interface.

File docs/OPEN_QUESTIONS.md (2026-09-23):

# SV-16 Rev A — Open Architectural Questions

This document records all architectural questions, ambiguities, and design choices requiring resolution before finalizing the hardware implementation.

Per **Rule 1 (Do not invent architecture)**:
- No architectural assumption may be treated as permanent unless formally resolved.
- Where a provisional choice is made to allow incremental progress, it is explicitly marked as `[PROVISIONAL]`.
- If a decision affects compatibility between hardware and firmware, dependent implementation must halt until resolved.

---

## Open Decisions Tracking Table

| ID | Title | Impact Area | Status | Provisional Choice | Target Resolution |
| :--- | :--- | :--- | :--- | :--- | :--- |
| **OQ-01** | Instruction Word Width & Multi-word Encoding | ISA / Decoder / PC | **PROVISIONAL** | Fixed 16-bit instructions for ALU/branch; 2-word (32-bit) for 16-bit immediate load / direct jump | Freeze in Phase 1 |
| **OQ-02** | Endianness & Memory Alignment | System Bus / Memory | **PROVISIONAL** | 16-bit word-addressed memory internally; little-endian byte ordering for external 8-bit bus/UART | Freeze in Phase 1 |
| **OQ-03** | Status Register Flag Bit Assignment | ALU / CPU / Status Reg | **PROVISIONAL** | Bit 0: Z (Zero), Bit 1: C (Carry), Bit 2: N (Negative), Bit 3: V (Overflow), Bits 4-7: Reserved | Freeze in Phase 1 |
| **OQ-04** | Division-by-Zero Handling | ALU / CPU / Interrupt | **PROVISIONAL** | Set V flag, return quotient 0xFFFF, remainder unchanged; optional fault trap in future | Freeze in Phase 1 |
| **OQ-05** | Multiplication Result Bit-Width | ALU / Reg File | **PROVISIONAL** | Single 16-bit register destination receives lower 16 bits; optional high-word stored in dedicated MAC/high reg or separate instruction (`MULH`) | Freeze in Phase 1 |
| **OQ-06** | Stack Growth Direction & Addressing | CPU / SP / Bus | **PROVISIONAL** | Downward growing (full-descending: SP decrements before push, increments after pop) | Freeze in Phase 1 |
| **OQ-07** | Reset Vector Address & Stack Pointer Initial Value | CPU / Reset FSM | **PROVISIONAL** | Reset PC = `0x0000`; Initial SP = `0x0FFE` (top of internal 4KB BRAM) | Freeze in Phase 1 |
| **OQ-08** | Memory Architecture: Harvard vs Von Neumann | Bus / Cache / Memory | **PROVISIONAL** | Unified Von Neumann memory-mapped space on single synchronous bus with multi-cycle arbiter | Freeze in Phase 1 |
| **OQ-09** | Default Master Clock Frequency on Lattice ECP5 | Clock / Constraints | **PROVISIONAL** | 25.0 MHz baseline operating clock generated from onboard oscillator (via internal PLL or direct) | Freeze in Phase 2 |
| **OQ-10** | Peripheral Bus Protocol | System Bus / Peripherals | **PROVISIONAL** | Synchronous wishbone-like strobe/ack or simple valid/ready 16-bit bus | Freeze in Phase 1 |

---

## Detailed Question Breakdowns

### OQ-01: Instruction Word Width & Multi-word Encoding
- **Issue**: SV-16 is a 16-bit architecture. An instruction must specify opcode, source registers, destination register, and potentially immediate values. In 16 bits, encoding `OP (4 bits) + Rd (3 bits) + Rs1 (3 bits) + Rs2 (3 bits)` leaves 3 bits. However, a 16-bit constant (`MOV R0, #0x1234`) cannot fit into a single 16-bit instruction.
- **Provisional Recommendation**:
  - Class 1: Single-word 16-bit instructions (register-register ALU, short branches, single register operations).
  - Class 2: Two-word 32-bit instructions (immediate loads with 16-bit constants, absolute long jumps, direct memory load/store). The instruction fetch FSM fetches the second 16-bit word in the subsequent cycle.

### OQ-02: Endianness & Memory Alignment
- **Issue**: Does memory address 16-bit words (word-addressed `0x0000` to `0xFFFF` = 64k 16-bit words) or 8-bit bytes (byte-addressed `0x0000` to `0xFFFF` = 64k bytes = 32k words)?
- **Provisional Recommendation**: Word-addressed internally (`addr[15:0]` accesses a 16-bit data word directly) avoids unaligned access complexity in Rev A. If byte addressing is adopted, unaligned access must be strictly defined (e.g. traps or ignored LSB). Word addressing simplifies BRAM and peripheral address decoders significantly for Rev A.

### OQ-03: Status Register Bit Assignment
- **Issue**: Standardizing bit positions of `Z`, `C`, `N`, `V` in `SR`.
- **Provisional Recommendation**:
  - `SR[0]`: `Z` (Zero)
  - `SR[1]`: `C` (Carry / Unsigned overflow)
  - `SR[2]`: `N` (Negative / Sign bit)
  - `SR[3]`: `V` (Overflow / Signed overflow)
  - `SR[7:4]`: Interrupt enable / status flags (`IE` = bit 7)
  - `SR[15:8]`: Reserved (read as 0)

### OQ-04: Division by Zero Behavior
- **Issue**: Required behavior when `DIV Rd, Rs` is executed with `Rs == 0`.
- **Provisional Recommendation**:
  - Zero flag `Z = 0`, Carry `C = 0`, Negative `N = 0`, Overflow `V = 1`.
  - Quotient in destination register becomes `0xFFFF` (or saturated value `0x0000`).
  - No hardware lockup; CPU continues executing next instruction.

### OQ-05: 16-bit Multiplier Width
- **Issue**: 16-bit × 16-bit produces a 32-bit result.
- **Provisional Recommendation**:
  - Standard `MUL Rd, Rs` stores lower 16 bits in `Rd` (sufficient for most motor PWM and control loop calculations).
  - Dedicated `MULH Rd, Rs` (or a high register) can capture the upper 16 bits if needed.
  - Lattice ECP5 contains 18×18 sysDSP slices which execute 16×16 single-cycle multiplication trivially in hardware.

### OQ-06: Stack Pointer Semantics
- **Issue**: Push/pop ordering, pre-decrement vs post-decrement.
- **Provisional Recommendation**: Full descending stack:
  - `PUSH Rs`: `SP <= SP - 1`; `MEM[SP] <= Rs`
  - `POP Rd`: `Rd <= MEM[SP]`; `SP <= SP + 1`
  - Stack top is valid data.

### OQ-07: Reset Vector & Memory Bounds
- **Issue**: Power-up entry point and BRAM allocation.
- **Provisional Recommendation**:
  - Power-up PC = `0x0000` (Vector 0: Reset Handler).
  - Vector 1: `0x0001` (Timer Interrupt).
  - Vector 2: `0x0002` (UART Interrupt).
  - Vector 3: `0x0003` (External/GPIO Interrupt).
  - Initial `SP` loaded to `0x0FFE` by reset or startup code.

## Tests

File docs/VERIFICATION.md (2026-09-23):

# SV-16 Rev A — Verification Strategy and Test Plan

---

## 1. Verification Strategy

SV-16 Rev A enforces strict bottom-up verification (Rule 2 and Rule 40):
1. **Module Unit Testing**:
   - Every RTL module must have an accompanying self-checking testbench (`module_tb.sv` or equivalent).
   - Testbenches check nominal behavior, boundary cases, and invalid inputs.
2. **Subsystem Integration Testing**:
   - Datapath testing: Register File + ALU + SR integration.
   - Memory Subsystem testing: Bus arbiter + RAM + Bus timing.
3. **CPU Execution Verification**:
   - Automated instruction execution tests: verifying every opcode and flag setting against expected architectural state.
   - Self-checking firmware programs run in simulation before FPGA bitstream generation.
4. **Automated Regression Suite**:
   - Executable via command line script (`python3 scripts/run_tests.py` / `make test`).
   - Every git commit must maintain a clean regression run without errors.

---

## 2. Test Plan Matrix

| Module | Testbench Path | Key Corner Cases to Verify | Status |
| :--- | :--- | :--- | :--- |
| **Register File** (`sv16_regfile`) | `simulation/unit/sv16_regfile_tb.sv` | Simultaneous read of same reg, write enable 0 vs 1, read-during-write | Pending Phase 3 |
| **ALU** (`sv16_alu`) | `simulation/unit/sv16_alu_tb.sv` | 0, `0xFFFF`, `0x7FFF`, signed overflow, carry, shift amounts (0, 1, 15, 16), DIV by 0 | Pending Phase 4 |
| **Status Register** (`sv16_status_reg`) | `simulation/unit/sv16_status_reg_tb.sv` | Flag update gating, bit positioning, clear/set | Pending Phase 5 |
| **Program Counter** (`sv16_pc`) | `simulation/unit/sv16_pc_tb.sv` | Reset to 0x0000, increment, target branch load, hold on stall | Pending Phase 6 |
| **Instruction Decoder** (`sv16_decoder`) | `simulation/unit/sv16_decoder_tb.sv` | All 16 primary opcodes, extended sub-opcodes, illegal opcodes | Pending Phase 7 |
| **Control Unit** (`sv16_control_unit`) | `simulation/unit/sv16_control_unit_tb.sv`| FSM transitions, bus wait-states, multi-cycle sequencing | Pending Phase 8 |
| **Minimal CPU Core** (`sv16_cpu`) | `simulation/regression/sv16_cpu_tb.sv` | Execute test program (`MOV`, `ADD`, `SUB`, `JMP`) | Pending Phase 9 |
| **Memory Bus Subsystem** | `simulation/regression/sv16_soc_tb.sv` | RAM read/write, memory-mapped peripheral read/write | Pending Phase 10 |
| **GPIO Controller** | `simulation/unit/sv16_gpio_tb.sv` | Pin direction, pin read, atomic SET/CLR | Pending Phase 13 |
| **Timer 0** | `simulation/unit/sv16_timer_tb.sv` | Prescaler clock division, compare match, auto-reload, interrupt | Pending Phase 14 |
| **PWM Controller 0** | `simulation/unit/sv16_pwm_tb.sv` | Frequency, 0% duty, 50% duty, 100% duty, emergency fault shutdown | Pending Phase 15 |
| **UART 0** | `simulation/unit/sv16_uart_tb.sv` | TX serial framing, RX framing, baud generator precision | Pending Phase 16 |

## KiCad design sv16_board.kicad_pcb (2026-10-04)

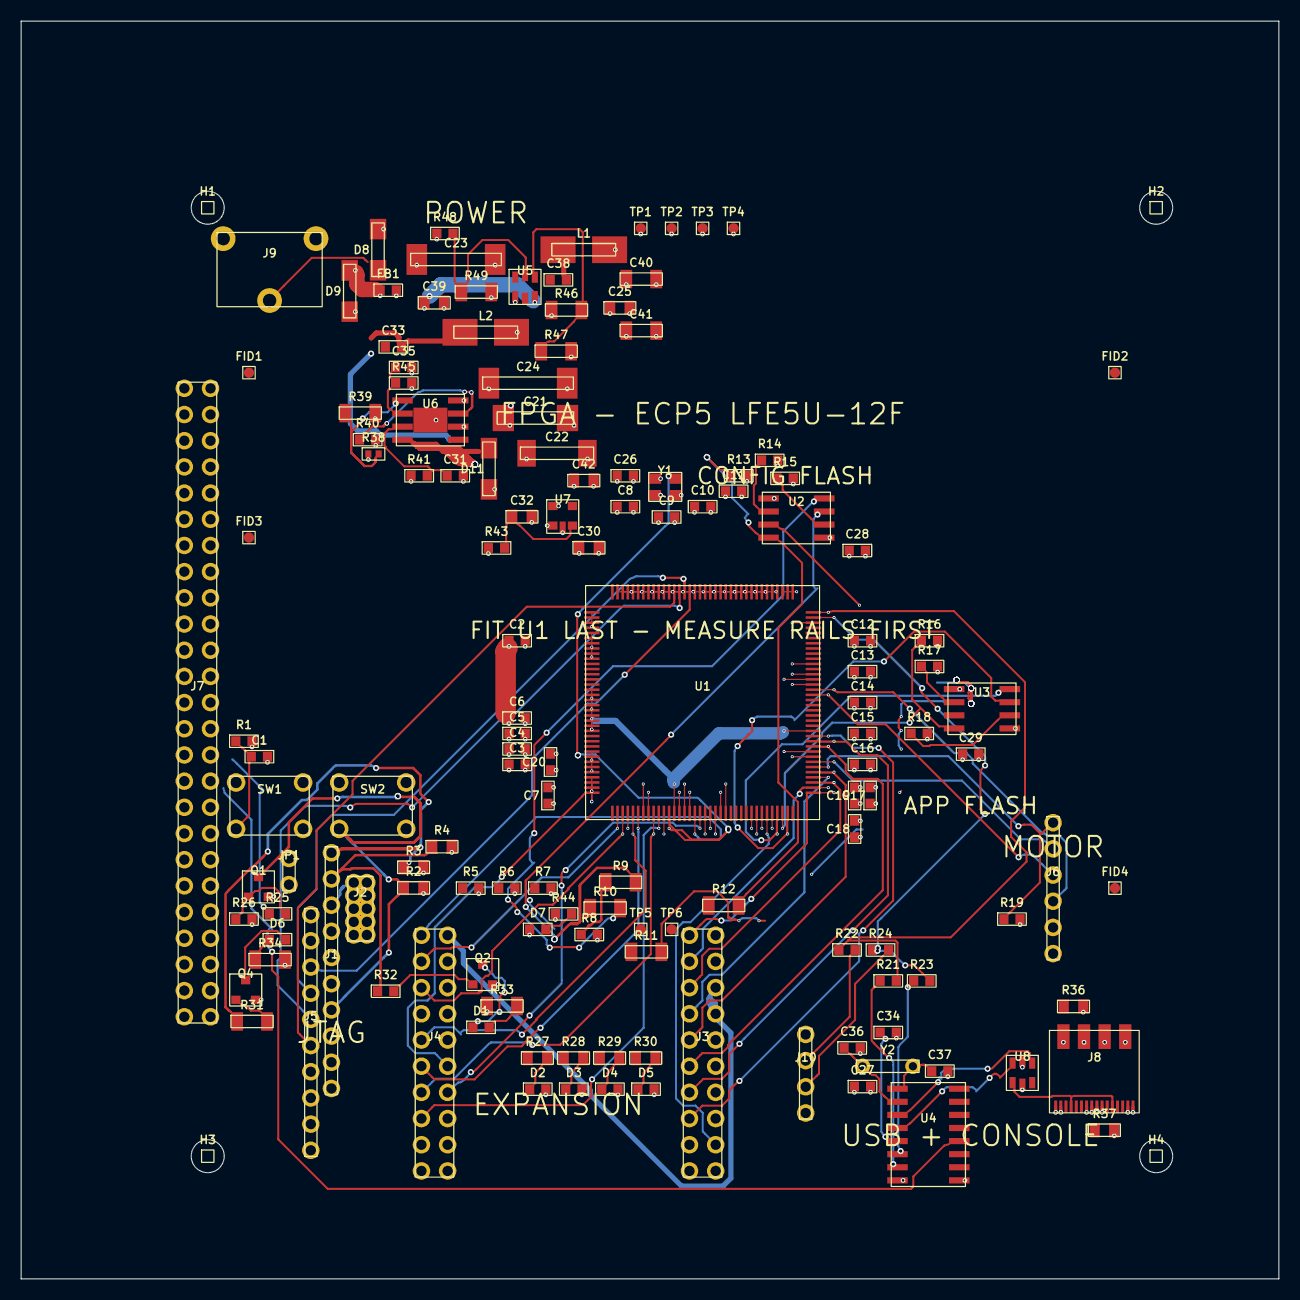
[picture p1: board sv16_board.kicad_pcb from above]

Board: 4 copper layers, 122.0 x 122.0 mm, 141 parts (0 on the bottom side), 118 nets.

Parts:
C1, C2, C3, C4, C5, C6, C7, C8, C9, C10, C11, C12, C13, C14, C15, C16, C17, C18, C19, C20, C26, C27, C28, C29, C33, C34, C35, C36, C37, C38: 100nF; C_0603_1608Metric
C21: 100uF 25V tant; CP_EIA-7343-31_Kemet-D
C22: 22uF 63V; CP_Elec_6.3x5.4
C23: 470uF 25V; CP_Elec_8x10.5
C24: 220uF 16V; CP_Elec_8x10.5
C25, C30, C39, C42: 10uF; C_0805_2012Metric
C31: 470nF; C_0603_1608Metric
C32: 470nF; C_0805_2012Metric
C40, C41: 22uF; C_1206_3216Metric
D1, D2, D3, D4, D5: LED green; LED_0603_1608Metric
D6, D7: LED red; LED_0603_1608Metric
D8, D9, D11: SS34; D_SMA
FB1: 600R @100MHz; L_0603_1608Metric
FID1: FID1; Fiducial_1mm_Mask2mm
FID2: FID2; Fiducial_1mm_Mask2mm
FID3: FID3; Fiducial_1mm_Mask2mm
FID4: FID4; Fiducial_1mm_Mask2mm
H1: H1; MountingHole_3.2mm_M3
H2: H2; MountingHole_3.2mm_M3
H3: H3; MountingHole_3.2mm_M3
H4: H4; MountingHole_3.2mm_M3
J1: JTAG; PinHeader_1x10_P2.54mm_Vertical
J2: JTAG-1.27; PinHeader_2x05_P1.27mm_Vertical
J3: EXP-A; PinHeader_2x10_P2.54mm_Vertical
J4: EXP-B; PinHeader_2x10_P2.54mm_Vertical
J5: EXP-C; PinHeader_1x10_P2.54mm_Vertical
J6: MOTOR; PinHeader_1x06_P2.54mm_Vertical
J7: SPARE (not fitted); PinHeader_2x25_P2.54mm_Vertical
J8: USB-C; USB_C_Receptacle_HRO_TYPE-C-31-M-12
J9: 7-12 V; BarrelJack_CUI_PJ-102AH_Horizontal
J10: CONSOLE; PinHeader_1x04_P2.54mm_Vertical
JP1: DTR ENABLE; PinHeader_1x02_P2.54mm_Vertical
L1, L2: 10 uH; L_Sunlord_MWSA0518_5.4x5.2mm
Q1: 2N7002; SOT-23
Q2: BC817; SOT-23
Q4: BC807; SOT-23
R1: R1; R_0603_1608Metric
R2: R2; R_0805_2012Metric
R3: R3; R_0805_2012Metric
R4: R4; R_0805_2012Metric
R5: R5; R_0603_1608Metric
R6: R6; R_0603_1608Metric
R7: R7; R_0603_1608Metric
R8: R8; R_0603_1608Metric
R9: R9; R_1206_3216Metric
R10: R10; R_1206_3216Metric
R11: R11; R_1206_3216Metric
R12: R12; R_1206_3216Metric
R13: R13; R_0603_1608Metric
R14: R14; R_0603_1608Metric
R15: R15; R_0603_1608Metric
R16: R16; R_0603_1608Metric
R17: R17; R_0603_1608Metric
R18: R18; R_0603_1608Metric
R19: R19; R_0603_1608Metric
R21: R21; R_0603_1608Metric
R22: R22; R_0603_1608Metric
R23: R23; R_0603_1608Metric
R24: R24; R_0603_1608Metric
R25: R25; R_0603_1608Metric
R26: R26; R_0603_1608Metric
R27: R27; R_0805_2012Metric
R28: R28; R_0805_2012Metric
R29: R29; R_0805_2012Metric
R30: R30; R_0805_2012Metric
R31: R31; R_1206_3216Metric
R32: R32; R_0603_1608Metric
R33: R33; R_1206_3216Metric
R34: R34; R_1206_3216Metric
R36, R37: 5.1k; R_0805_2012Metric
R38: 12.4k; R_0402_1005Metric
R39, R46, R49: 33k; R_1206_3216Metric
R40, R41, R43, R48: 100k; R_0603_1608Metric
R44: R44; R_0603_1608Metric
R45: 10k; R_0603_1608Metric
R47: 10k; R_1206_3216Metric
SW1: RESET; SW_PUSH_6mm
SW2: RECONFIG; SW_PUSH_6mm
TP1: 3V3; TestPoint_Pad_D1.0mm
TP2: 2V5; TestPoint_Pad_D1.0mm
TP3: 1V1; TestPoint_Pad_D1.0mm
TP4: GND; TestPoint_Pad_D1.0mm
TP5: DONE; TestPoint_Pad_D1.0mm
TP6: INITN; TestPoint_Pad_D1.0mm
U1: LFE5U-12F-6TG144C; LQFP-144_20x20mm_P0.5mm
U2, U3: W25Q64JVSSIQ; SOIC-8_5.23x5.23mm_P1.27mm
U4: CH340G; SOIC-16_3.9x9.9mm_P1.27mm
U5: AP62300TWU-7; SOT-23-6
U6: MP1584EN; SOIC-8-1EP_3.9x4.9mm_P1.27mm_EP2.41x3.3mm
U7: LP5907MFX-2.5; SOT-23-5
U8: USBLC6-2SC6; SOT-23-6
Y1: 25 MHz ACTIVE XO (4-pin); Oscillator_SMD_Abracon_ASE-4Pin_3.2x2.5mm
Y2: 12 MHz (CH340G clock); Crystal_HC49-4H_Vertical

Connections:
1V1: C2.1, C3.1, C4.1, C5.1, C6.1, C7.1, C21.1, L2.2, R38.1, TP3.1, U1.20, U1.29, U1.38, U1.66, U1.83, U1.130
2V5: C8.1, C9.1, C10.1, C11.1, C22.1, C42.1, TP2.1, U1.17, U1.53, U1.96, U1.132, U7.5
3V3: C12.1, C13.1, C14.1, C15.1, C16.1, C17.1, C18.1, C19.1, C20.1, C24.1, C25.1, C26.1, C27.1, C28.1, C29.1, C30.1, C40.1, C41.1, D2.2, D3.2, D4.2, D5.2, J1.1, J2.1, J3.1, J4.1, J5.10, J10.1, L1.2, Q4.2, R1.2, R2.2, R3.2, R4.2, R5.2, R8.2, R13.2, R14.2, R15.2, R16.2, R17.2, R18.2, R19.2, R33.1, R43.1, R44.1, R46.1, TP1.1, U1.9, U1.16, U1.36, U1.43, U1.70, U1.86, U1.100, U1.122, U1.137, U2.8, U3.8, U4.16, U7.1, Y1.1, Y1.4
5V_USB: J3.17, J3.18, J4.20
A0: J5.1, U1.45
A1: J5.2, R11.1, U1.46
A2: J5.3, R10.1, U1.47
A3: J5.4, U1.48
A4: J5.5, R12.1, U1.49
A5: J5.6, U1.50
A6: J5.7, U1.51
A7: J5.8, U1.52
A8: J3.3, U1.97
A9: J3.4, U1.98
A10: J3.5, U1.99
A11: J3.6, U1.104
A12: J3.7, U1.105
A13: J3.8, U1.106
A14: J3.9, U1.107
A15: J3.10, U1.108
B0: J4.3, U1.135
B1: J4.4, U1.136
B2: J4.5, U1.139
B3: J4.6, U1.140
B4: J4.7, U1.141
B5: J4.8, U1.142
B6: J4.9, U1.143
B7: J4.10, U1.128
B8: J4.11, U1.124
B9: J4.12, U1.125
B10: J4.13, U1.126
B11: J4.14, U1.127
B12: J4.15, U1.1
B13: J4.16, U1.2
B14: J4.17, U1.3
B15: J4.18, U1.4
CC1: J8.A5, R36.1
CC2: J8.B5, R37.1
CCLK: R8.1, R9.1, U1.54
CFG_0: R6.1, U1.62
CFG_1: R5.1, U1.59
CFG_2: R7.1, U1.58
D1_A: D1.2, R33.2
D6_K: D6.1, R34.1
D7_A: D7.2, R44.2
DONE: J1.9, R4.1, R32.1, TP5.1, U1.56
DTR_F: JP1.2, R25.1
FB_1V1: R38.2, R39.1, U6.4
GND: C1.2, C2.2, C3.2, C4.2, C5.2, C6.2, C7.2, C8.2, C9.2, C10.2, C11.2, C12.2, C13.2, C14.2, C15.2, C16.2, C17.2, C18.2, C19.2, C20.2, C21.2, C22.2, C23.2, C24.2, C25.2, C26.2, C27.2, C28.2, C29.2, C30.2, C31.2, C32.2, C34.2, C35.2, C36.2, C37.2, C39.2, C40.2, C41.2, C42.2, D7.1, D11.2, J1.7, J2.6, J2.10, J3.2, J3.15, J3.16, J3.19, J3.20, J4.2, J4.19, J5.9, J6.2, J8.A1, J8.A12, J8.B1, J8.B12, J8.S1, J8.S2, J8.S3, J8.S4, J9.2, J10.4, Q1.2, Q2.2, R6.2, R7.2, R26.2, R34.2, R36.2, R37.2, R39.2, R40.2, R45.2, R47.2, R49.2, SW1.2, SW2.2, TP4.1, U1.8, U1.15, U1.21, U1.32, U1.42, U1.65, U1.75, U1.85, U1.87, U1.101, U1.123, U1.129, U1.131, U1.138, U2.4, U3.4, U4.1, U5.1, U6.5, U6.9, U7.2, U8.2, Y1.2
INITN: J1.10, R3.1, R31.1, TP6.1, U1.55
J9_VIN: D8.2, J9.1
J10_RX: J10.3, R22.2
J10_TX: J10.2, R24.2
PROGRAMN: J1.4, Q1.3, R2.1, SW2.1, U1.57
Q1_G: Q1.1, R25.2, R26.1
Q2_B: Q2.1, R32.2
Q2_C: D1.1, Q2.3
Q4_B: Q4.1, R31.2
Q4_C: D6.2, Q4.3
TCK: J1.8, J2.5, U1.63
TDI: J1.3, J2.3, U1.61
TDO: J1.2, J2.4, U1.60
TMS: J1.6, J2.2, U1.64
U2_CLK: R9.2, U2.6
U2_CS: R12.2, R13.1, U2.1
U2_DI: R10.2, U2.5
U2_DO: R11.2, U2.2
U2_HOLD: R15.1, U2.7
U2_WP: R14.1, U2.3
U3_HOLD: R18.1, U3.7
U3_WP: R17.1, U3.3
U4_DTR: JP1.1, U4.13
U4_RXD: R23.1, U4.3
U4_TXD: R21.1, U4.2
U4_V3: C34.1, U4.4
U5_BST: C38.1, U5.6
U5_EN: R48.2, R49.1, U5.5
U5_FB: R46.2, R47.1, U5.4
U5_SW: C38.2, L1.1, U5.2
U6_BST: C33.1, U6.8
U6_COMP: C35.1, R45.1, U6.3
U6_EN: C31.1, R41.2, U6.2
U6_FREQ: R40.1, U6.6
U6_SW: C33.2, D11.1, L2.1, U6.1
U7_EN: C32.1, R43.2, U7.3
USB_DN: J8.A7, J8.B7, U8.3
USB_DN_F: U4.6, U8.4
USB_DP: J8.A6, J8.B6, U8.1
USB_DP_F: U4.5, U8.6
USB_VBUS: D9.2, J8.A4, J8.A9, J8.B4, J8.B9, U8.5
VM_IN: C23.1, C39.1, FB1.2, J6.1, R41.1, R48.1, U5.3, U6.7
VM_IN_RAW: D8.1, D9.1, FB1.1
Y2_XI: C36.1, U4.7, Y2.1
Y2_XO: C37.1, U4.8, Y2.2
clk_25m: U1.133, Y1.3
ext_rst_n: C1.1, R1.1, SW1.1, U1.134
flash_cs_n: R16.1, U1.111, U3.1
flash_miso: U1.113, U3.2
flash_mosi: U1.112, U3.5
flash_sck: U1.110, U3.6
led0: R27.1, U1.39
led0_k: D2.1, R27.2
led1: R28.1, U1.40
led1_k: D3.1, R28.2
led2: R29.1, U1.41
led2_k: D4.1, R29.2
led3: R30.1, U1.44
led3_k: D5.1, R30.2
motor_dir1: J6.4, U1.89
motor_dir2: J6.5, U1.102
motor_fault_n: J6.6, R19.1, U1.103
pwm_out: J6.3, U1.88
spi0_cs_n: J3.11, U1.115
spi0_miso: J3.14, U1.117
spi0_mosi: J3.13, U1.116
spi0_sck: J3.12, U1.114
uart_rx: R21.2, R22.1, U1.73
uart_tx: R23.2, R24.1, U1.74

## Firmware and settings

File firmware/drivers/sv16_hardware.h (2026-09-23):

/*
 * SV-16 Rev A — Low-Level Hardware Peripheral Header
 * Register definitions, peripheral base addresses, and hardware drivers
 */

#ifndef SV16_HARDWARE_H
#define SV16_HARDWARE_H

#include <stdint.h>

// Peripheral Base Addresses (Word Addresses)
#define GPIO_BASE   ((volatile uint16_t*)0xF010)
#define TIMER_BASE  ((volatile uint16_t*)0xF020)
#define PWM_BASE    ((volatile uint16_t*)0xF030)
#define UART_BASE   ((volatile uint16_t*)0xF040)

// GPIO Register Offsets
#define GPIO_DATA   (GPIO_BASE[0])
#define GPIO_DIR    (GPIO_BASE[1])
#define GPIO_SET    (GPIO_BASE[2])
#define GPIO_CLR    (GPIO_BASE[3])

// Timer 0 Register Offsets
#define TMR0_CNT    (TIMER_BASE[0])
#define TMR0_CMP    (TIMER_BASE[1])
#define TMR0_CTRL   (TIMER_BASE[2])
#define TMR0_STAT   (TIMER_BASE[3])

// PWM 0 Register Offsets
#define PWM0_PERIOD (PWM_BASE[0])
#define PWM0_DUTY   (PWM_BASE[1])
#define PWM0_CTRL   (PWM_BASE[2])
#define PWM0_STAT   (PWM_BASE[3])

// UART 0 Register Offsets
#define UART0_DATA  (UART_BASE[0])
#define UART0_STAT  (UART_BASE[1])
#define UART0_BAUD  (UART_BASE[2])
#define UART0_CTRL  (UART_BASE[3])

// --- High-Level Hardware Driver Functions ---

// GPIO Driver
static inline void gpio_init(uint16_t output_mask) {
    GPIO_DIR = output_mask;
}

static inline void gpio_write(uint16_t val) {
    GPIO_DATA = val;
}

static inline void gpio_set_bit(uint8_t pin) {
    GPIO_SET = (1 << pin);
}

static inline void gpio_clr_bit(uint8_t pin) {
    GPIO_CLR = (1 << pin);
}

// PWM Motor Control Driver
static inline void pwm_motor_init(uint16_t period) {
    PWM0_PERIOD = period;
    PWM0_DUTY   = 0; // Motor off initially
    PWM0_CTRL   = 1; // Enable PWM
}

static inline void pwm_set_speed(uint16_t duty) {
    PWM0_DUTY = duty;
}

static inline void motor_set_direction(int dir) {
    if (dir > 0) {
        gpio_set_bit(4); // DIR1 = 1
        gpio_clr_bit(5); // DIR2 = 0
    } else if (dir < 0) {
        gpio_clr_bit(4); // DIR1 = 0
        gpio_set_bit(5); // DIR2 = 1
    } else {
        gpio_clr_bit(4); // Coast / Brake
        gpio_clr_bit(5);
    }
}

// UART Driver
static inline void uart_putc(char c) {
    while (!(UART0_STAT & 1)); // Wait for TX_READY
    UART0_DATA = (uint16_t)c;
}

static inline void uart_puts(const char* s) {
    while (*s) {
        uart_putc(*s++);
    }
}

#endif // SV16_HARDWARE_H

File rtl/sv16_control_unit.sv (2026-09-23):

// SV-16 Rev A — CPU Control Unit
// Module: sv16_control_unit
//
// Multi-cycle synchronous Finite State Machine (FSM):
//   S_FETCH     (0): Request instruction word from bus at PC
//   S_DECODE    (1): Latch IR, decode, check for 2-word instruction
//   S_FETCH_IMM (2): Fetch 2nd 16-bit word if LDI, JMP, or CALL
//   S_EXECUTE   (3): ALU operation, branch evaluation, compute effective addr
//   S_MEMORY    (4): Bus access for LOAD, STORE, PUSH, POP
//   S_WRITEBACK (5): Write register file / update status flags

`timescale 1ns / 1ps

module sv16_control_unit (
    input  logic        clk,
    input  logic        rst_n,

    // Decoder classification inputs
    input  logic [3:0]  opcode,
    input  logic [3:0]  cond,
    input  logic        is_alu_rr,
    input  logic        is_alu_imm,
    input  logic        is_ext_alu,
    input  logic        is_load,
    input  logic        is_store,
    input  logic        is_mov,
    input  logic        is_branch,
    input  logic        is_jmp,
    input  logic        is_call,
    input  logic        is_ret,
    input  logic        is_push,
    input  logic        is_pop,
    input  logic        is_cmp,
    input  logic        is_two_word,

    // Status flags from Status Register
    input  logic        flag_z,
    input  logic        flag_c,
    input  logic        flag_n,
    input  logic        flag_v,

    // Bus handshake
    input  logic        bus_ack,
    output logic        bus_req,
    output logic        bus_we,
    output logic        bus_addr_sel,  // 0 = PC, 1 = Memory Address (SP or Effective Addr)

    // PC Controls
    output logic        pc_inc,
    output logic        pc_load,
    output logic        pc_branch,

    // Datapath & Register File Controls
    output logic        ir_load,
    output logic        imm_load,
    output logic        reg_wen,
    output logic [1:0]  reg_wdata_sel, // 0 = ALU result, 1 = Memory read, 2 = Immediate, 3 = PC
    output logic        flag_update_en,
    output logic        alu_src_b_sel, // 0 = Register Rs2, 1 = Immediate

    // Stack pointer controls
    output logic        sp_dec,
    output logic        sp_inc,

    // State Output for Debug/Trace
    output logic [2:0]  fsm_state
);

    typedef enum logic [2:0] {
        S_FETCH     = 3'd0,
        S_DECODE    = 3'd1,
        S_FETCH_IMM = 3'd2,
        S_EXECUTE   = 3'd3,
        S_MEMORY    = 3'd4,
        S_WRITEBACK = 3'd5
    } state_e;

    state_e current_state, next_state;

    assign fsm_state = current_state;

    // Branch Condition Evaluation Logic
    logic branch_condition_met;
    always_comb begin
        case (cond)
            4'h0: branch_condition_met = 1'b1;                          // BRA (Always)
            4'h1: branch_condition_met = flag_z;                       // BEQ (Z == 1)
            4'h2: branch_condition_met = !flag_z;                      // BNE (Z == 0)
            4'h3: branch_condition_met = flag_c;                       // BC / BLO (C == 1)
            4'h4: branch_condition_met = !flag_c;                      // BNC / BHS (C == 0)
            4'h5: branch_condition_met = flag_n;                       // BN / BMI (N == 1)
            4'h6: branch_condition_met = !flag_n;                      // BP / BPL (N == 0)
            4'h7: branch_condition_met = flag_v;                       // BVS (V == 1)
            4'h8: branch_condition_met = !flag_v;                      // BVC (V == 0)
            4'h9: branch_condition_met = (flag_n ^ flag_v);            // BLT (N ^ V == 1)
            4'hA: branch_condition_met = !(flag_n ^ flag_v);           // BGE (N ^ V == 0)
            4'hB: branch_condition_met = (flag_z | (flag_n ^ flag_v)); // BLE
            4'hC: branch_condition_met = !(flag_z | (flag_n ^ flag_v));// BGT
            default: branch_condition_met = 1'b0;
        endcase
    end

    // Sequential State Register
    always_ff @(posedge clk or negedge rst_n) begin
        if (!rst_n) begin
            current_state <= S_FETCH;
        end else begin
            current_state <= next_state;
        end
    end

    // Next-State Logic
    always_comb begin
        next_state = current_state;

        case (current_state)
            S_FETCH: begin
                if (bus_ack) begin
                    next_state = S_DECODE;
                end
            end

            S_DECODE: begin
                if (is_two_word) begin
                    next_state = S_FETCH_IMM;
                end else begin
                    next_state = S_EXECUTE;
                end
            end

            S_FETCH_IMM: begin
                if (bus_ack) begin
                    next_state = S_EXECUTE;
                end
            end

            S_EXECUTE: begin
                if (is_load || is_store || is_push || is_pop || is_call || is_ret) begin
                    next_state = S_MEMORY;
                end else if (is_alu_rr || is_alu_imm || is_ext_alu || is_mov) begin
                    next_state = S_WRITEBACK;
                end else begin
                    // JMP, Branch, CMP, NOP, CTRL
                    next_state = S_FETCH;
                end
            end

            S_MEMORY: begin
                if (bus_ack) begin
                    if (is_load || is_pop) begin
                        next_state = S_WRITEBACK;
                    end else begin
                        next_state = S_FETCH;
                    end
                end
            end

            S_WRITEBACK: begin
                next_state = S_FETCH;
            end

            default: next_state = S_FETCH;
        endcase
    end

    // Output Control Signals
    always_comb begin
        // Safe Defaults
        bus_req         = 1'b0;
        bus_we          = 1'b0;
        bus_addr_sel    = 1'b0; // 0 = PC
        pc_inc          = 1'b0;
        pc_load         = 1'b0;
        pc_branch       = 1'b0;
        ir_load         = 1'b0;
        imm_load        = 1'b0;
        reg_wen         = 1'b0;
        reg_wdata_sel   = 2'b00;
        flag_update_en  = 1'b0;
        alu_src_b_sel   = 1'b0;
        sp_dec          = 1'b0;
        sp_inc          = 1'b0;

        case (current_state)
            S_FETCH: begin
                bus_req      = 1'b1;
                bus_we       = 1'b0;
                bus_addr_sel = 1'b0; // Fetch from PC
                if (bus_ack) begin
                    ir_load = 1'b1;
                    pc_inc  = 1'b1;
                end
            end

            S_DECODE: begin
                // Register read occurs combinationally in decode
            end

            S_FETCH_IMM: begin
                bus_req      = 1'b1;
                bus_we       = 1'b0;
                bus_addr_sel = 1'b0; // Fetch immediate from PC
                if (bus_ack) begin
                    imm_load = 1'b1;
                    pc_inc   = 1'b1;
                end
            end

            S_EXECUTE: begin
                alu_src_b_sel = is_alu_imm;
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
